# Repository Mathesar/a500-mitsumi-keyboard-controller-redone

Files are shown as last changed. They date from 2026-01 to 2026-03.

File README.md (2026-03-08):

# Mitsumi PCB A-500 redone

This is a remake ("redone") of the Amiga 500 Mitsumi keyboard controller.

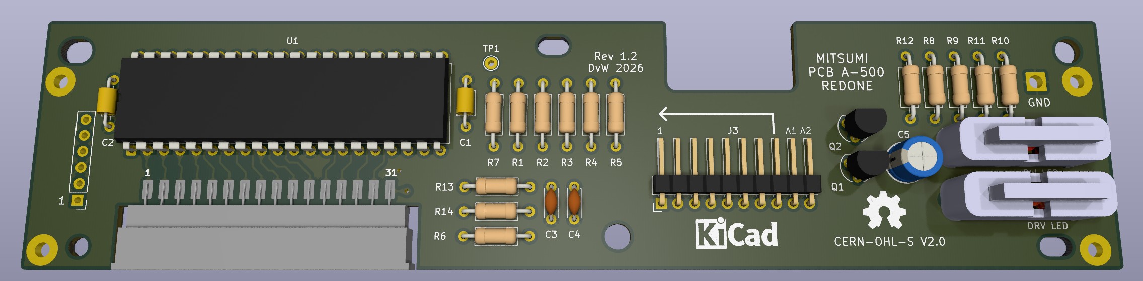
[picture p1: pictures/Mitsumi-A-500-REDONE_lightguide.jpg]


The original Amiga 500 uses a MOS 6570 microcontroller that is no longer produced and therefore getting exceedingly rare. They are also starting to fail, resulting in the dreaded "blinking CAPS-LOCK" issue. Since there was no open-source / open-hardware replacement design available I decided to make my own.

This is a completely new "from scratch" design that uses a Microchip [PIC18F4520](https://www.microchip.com/en-us/product/pic18f4520) microcontroller. I chose this type as it is available in a DIP40 package that is easy to solder by hand. It also gives this new redone keyboard controller a very similar look like the original controller. 

Lastly, what I like about the PIC18F4520 is that it is an 8bit microcontroller with modest capabilities not unlike the MOS 6570. It would bother me a bit to use a 50MHz+ 32bit ARM processor that is magnitudes faster than the Amiga's 68000 CPU just to scan a keyboard.

## Features

* Completely independent design.
* Fully compatible with the original Mitsumi keyboard controller.
* Debouncing filter.
* Anti-ghosting filter.
* Dimming power LED that also works on older Amiga 500 motherboard revisions.
* Through-hole design using currently available components for a retro look.
* Uses three 5mm x 2mm x 7mm LEDs instead of the unobtanium Commodore 15mm LED.
* Optionally, a 3D printed lightguide can be used to give a cleaner LED look.

## Molex ZIF connector

The original keyboard controller uses a Molex right angle ZIF connector to connect to the keyboard matrix membrane. This connector is very hard (impossible?) to get. I therefore used the straight version of this connector, the [Molex 39-53-2315](https://www.molex.com/en-us/products/part-detail/39532315). This connector is soldered on the edge of the circuitboard. This causes the entry point of the connector to sit lower than the original. This puts some strain on the flat cable and one should therefore take care when assembling the keyboard.

## LED brightness tuning

Modern LEDs are way brighter than the LEDs that Commodore used back in the days.
If the LEDs turn out too bright, they can be tuned by changing some resistor values.

### Drive LED

The drive LEDs can be tuned by simply changing resistor R12. Higher values lower the brightness.

### Power LED

The power LEDs are a bit special. One cannot simply use a larger than original current limiting resistor. This is because of the power LED dimming function on later revisions of the Amiga 500. Simply using a larger current limiting resistor would make the dimming hardly noticeable causing the power LEDs to always shine at seemingly full brightness.

To solve this, the circuit around Q1/Q2 has been added. This circuit detects when the LEDs should be dimmed or not. If the Amiga turns the LEDs on (full brightness on later revisions), only Q2 will conduct and deliver current to the LEDs via both R10 and R11. When the Amiga turns the LEDs off (dimmed on later revisions), only Q1 will conduct and current to the LEDs is only delivered via R10. The power LEDs will be dimmed.

For a good dimming effect, R10 should be about 4 times bigger than R11. This gives a current ratio of about 1:5.
In order to reduce or increase the brightness both resistors should thus be changed. Higher values lower the brightness.

## Building

The board is a completely through-hole design and should thus be easy to build. 
The BOM contains some partnumbers for the resistors but one can use any brand. None of the components are critical.

For the LEDs one can use 3 5mm x 2mm LEDs. These are still available. The top of these LEDs should sit above 12.3mm above the PCB. 
Alternatively, 3mm ("flat top") LEDs can be used combined with a 3D printed light guide. I had mine printed by JLC3DP using the 8001 "translucent" resin. The LEDs should be soldered close to the PCB to make this fit. Be aware though that the 8001 resin is not UV resistant on the long term. However, so far my light guides are holding up well.

To connect the keyboard controller to the main board a 300mm 8pin DuPont cable assembly can be used. The pinheader for this cable has 10 pins instead of 8. The extra pins are "auxiliary" pins meant for future expansions and not currently implemented. Therefore connect the keyboard cable only to pins 1..8 as indicated by the arrow.

## Firmware and programming

The firmware was developed using [MPLAB X ide v6.25](https://www.microchip.com/en-us/tools-resources/develop/mplab-x-ide).
The code is written in C for the [XC8 compiler](https://www.microchip.com/en-us/tools-resources/develop/mplab-xc-compilers/xc8).
These tools are freely available from [Microchip](https://www.microchip.com).

## Pictures

Picture of lightguide version mounted on an mechanical keyboard. The drive lightpipe has been removed to show the 3 flat top 3mm LEDs. You can also see how the groundstrap is supposed to connect. 
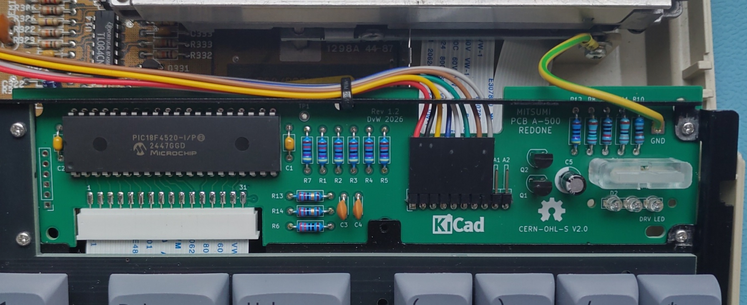
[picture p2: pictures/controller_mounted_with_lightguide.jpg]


Render of version using three 5mm x 2mm LEDs
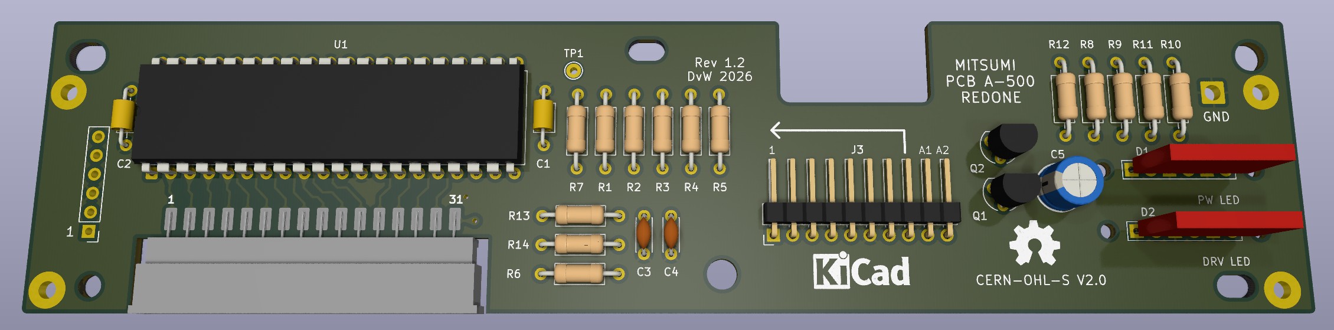
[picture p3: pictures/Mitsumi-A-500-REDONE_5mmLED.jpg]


Closeup of version with 5mm x 2mm LEDs. On this picture I glued the LEDs together using an UV curable glue. These LEDs were originally fully transparant but I sanded the tops with sandpaper to get a more diffuse look.
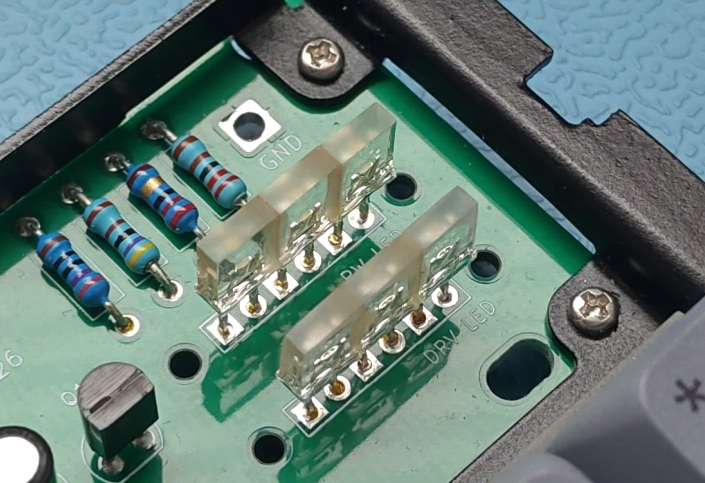
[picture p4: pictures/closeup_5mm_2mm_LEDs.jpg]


## Licenses

The hardware is licensed under [CERN OHL-S V2.0](https://cern-ohl.web.cern.ch/).
The firmware is licensed under [GNU GPL V3](https://www.gnu.org/licenses/gpl-3.0.en.html).

## Acknowledgements

The KiCad keyboard schematic symbol was originally done by [Scott Lawrence](https://github.com/BleuLlama/AmigaSchematics/tree/master/A500_kyb_Mitsumi).

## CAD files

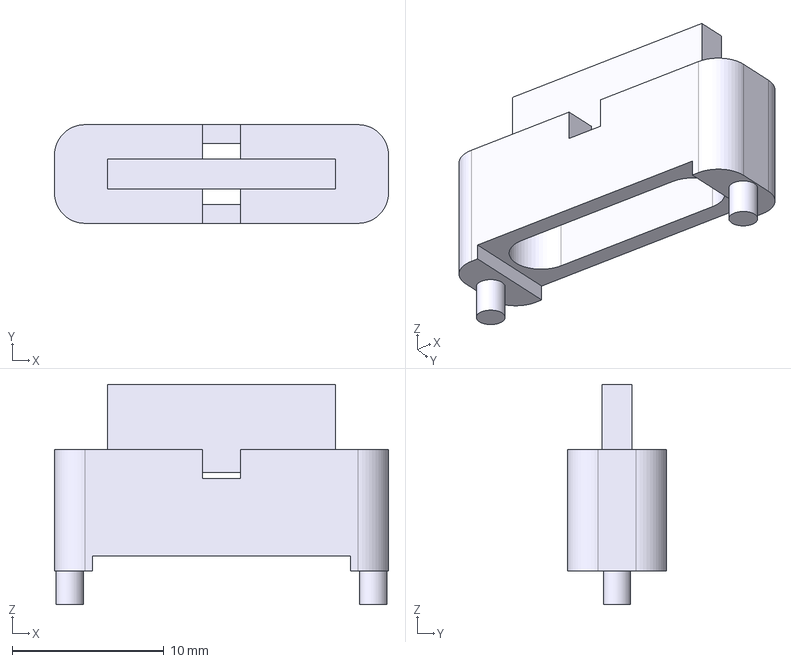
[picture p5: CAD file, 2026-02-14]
cad/lightpipe.step
22.0 x 6.50 x 14.5 mm

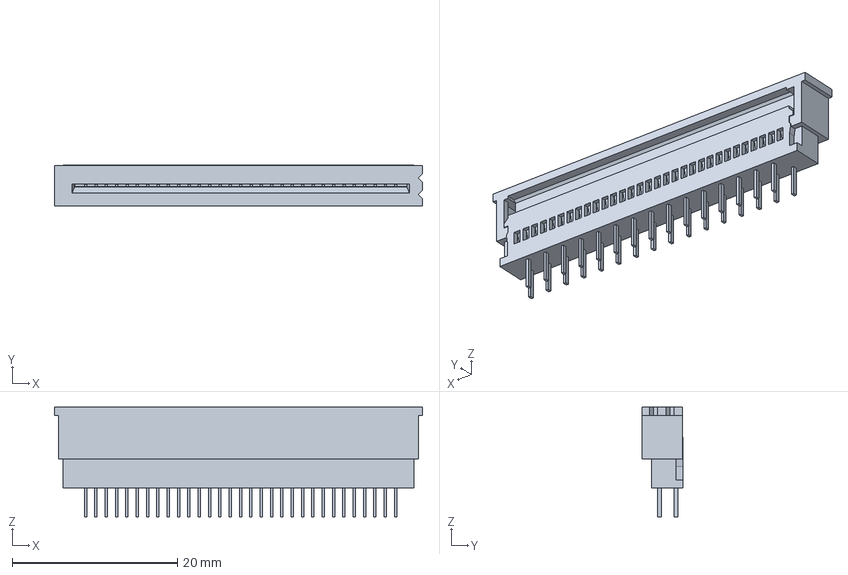
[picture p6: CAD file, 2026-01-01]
kicad/3D/0039532315.stp
44.5 x 5.00 x 13.3 mm

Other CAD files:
cad/lightpipe.FCStd

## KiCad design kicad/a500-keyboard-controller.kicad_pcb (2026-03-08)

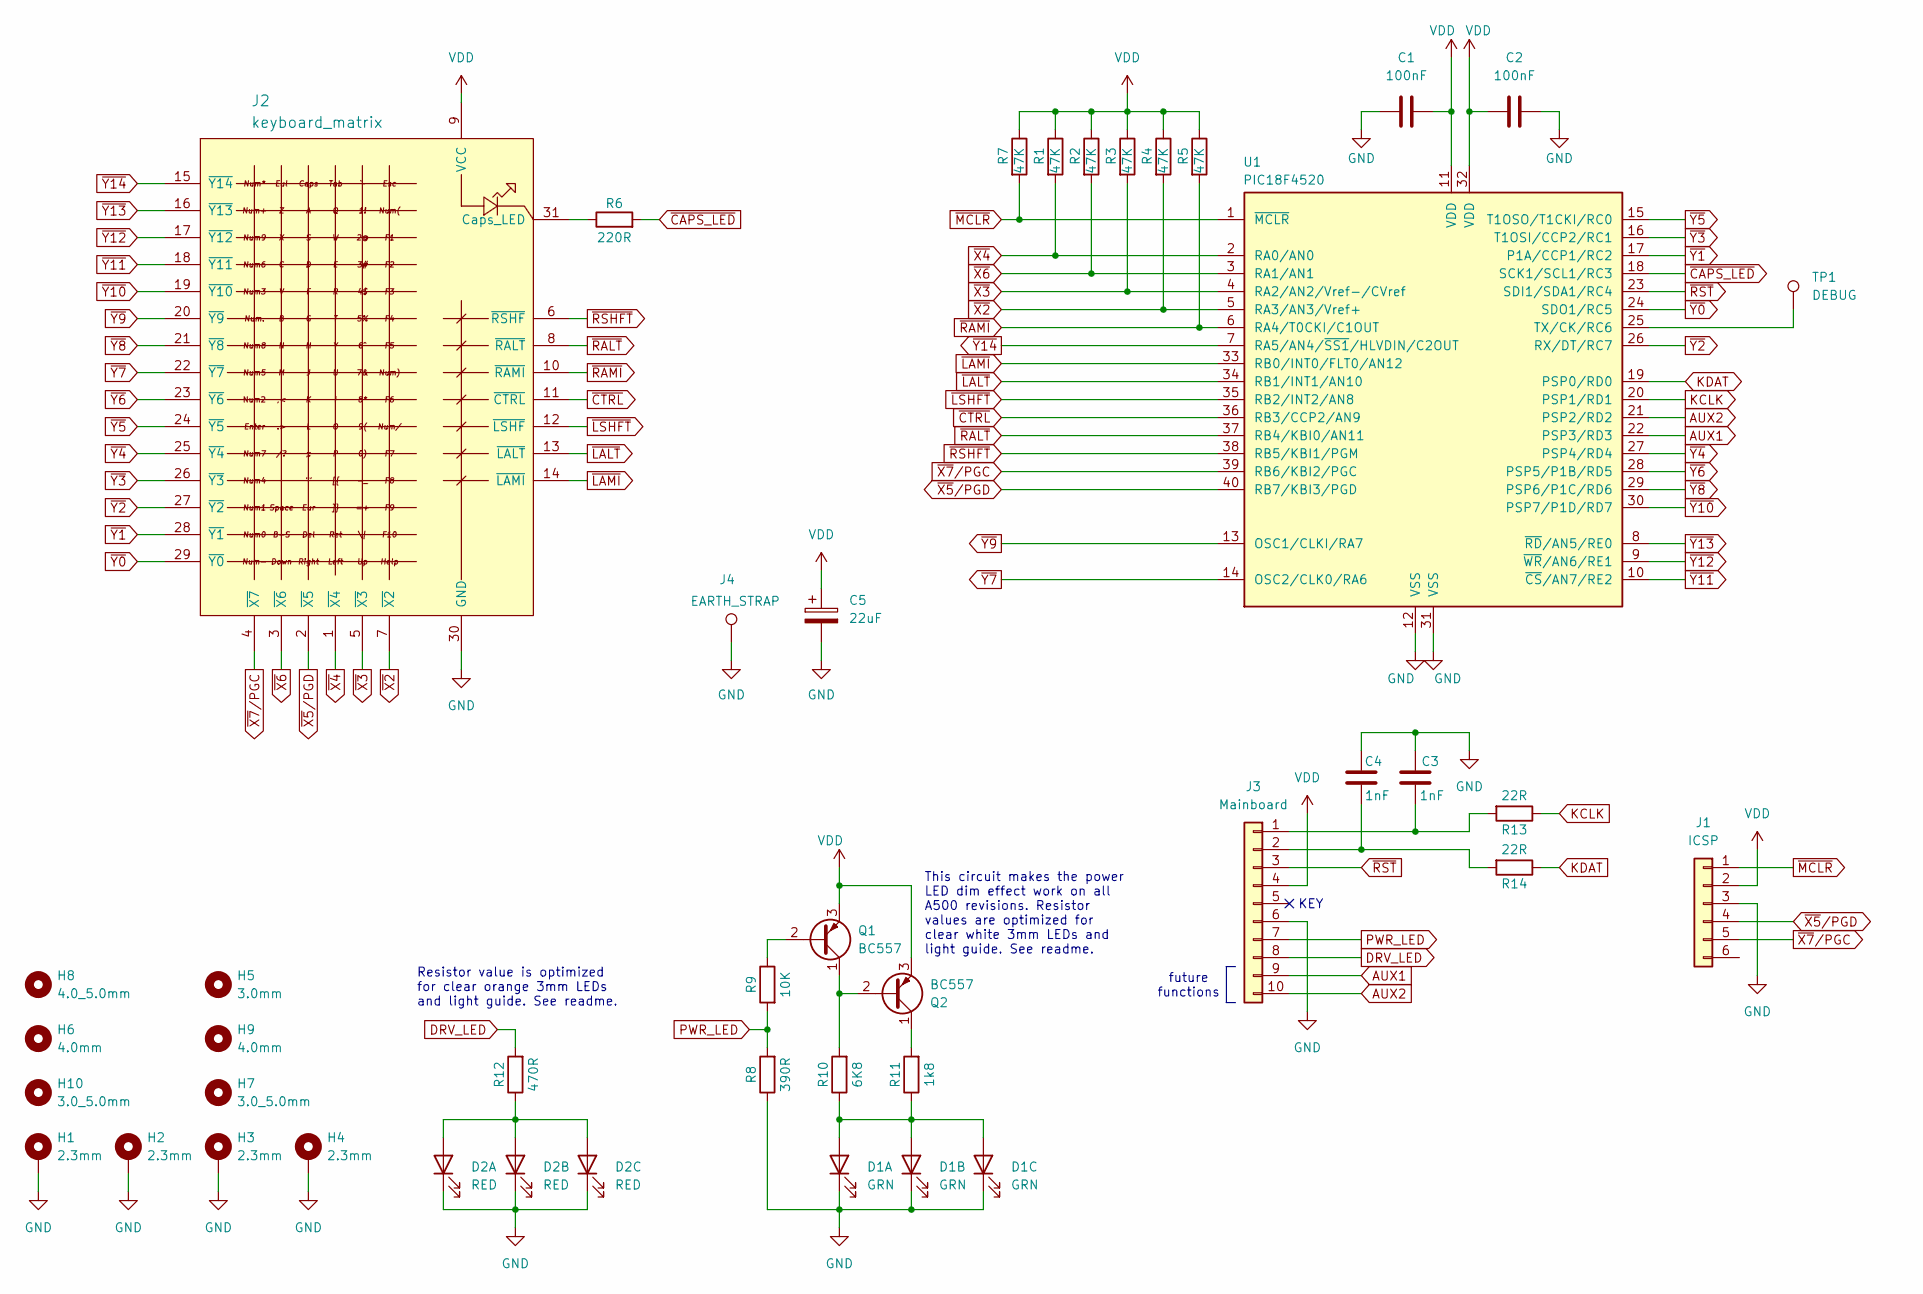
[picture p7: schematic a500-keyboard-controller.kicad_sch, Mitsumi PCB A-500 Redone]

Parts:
C1, C2: 100nF; C_Axial_L3.8mm_D2.6mm_P7.50mm_Horizontal; MPN A104K15X7RF5UAA
C3, C4: 1nF; C_Disc_D4.3mm_W1.9mm_P5.00mm; MPN D102K20Y5PH63J5R
C5: 22uF; CP_Radial_D6.3mm_P2.50mm; MPN EEA-GA1C220H
D1: GRN; A500_triple_LED_equivalent
D2: RED; A500_triple_LED_equivalent
H1, H2, H3, H4: 2.3mm; MountingHole_2.3mm_Pad
H5: 3.0mm; MountingHole_3mm
H6, H9: 4.0mm; MountingHole_4mm
H7, H10: 3.0_5.0mm; mountinghole_3.0_5.0
H8: 4.0_5.0mm; mountinghole_4.0_5.0
J1: ICSP; PinHeader_1x06_P2.54mm_Vertical
J2: keyboard_matrix; 39-53-2315; MPN 39-53-2315
J3: Mainboard; PinHeader_1x10_P2.54mm_Horizontal
J4: EARTH_STRAP; SolderWire-1.5sqmm_1x01_D1.7mm_OD3mm
Q1, Q2: BC557; TO-92_HandSolder_modified
R1, R2, R3, R4, R5, R7: 47K; R_Axial_DIN0207_L6.3mm_D2.5mm_P10.16mm_Horizontal; MPN MF0207FTE52-47K
R6: 220R; R_Axial_DIN0207_L6.3mm_D2.5mm_P10.16mm_Horizontal; MPN MF0207FTE52-220R
R8: 390R; R_Axial_DIN0207_L6.3mm_D2.5mm_P10.16mm_Horizontal; MPN MF0207FTE52-390R
R9: 10K; R_Axial_DIN0207_L6.3mm_D2.5mm_P10.16mm_Horizontal; MPN MF0207FTE52-10K
R10: 6K8; R_Axial_DIN0207_L6.3mm_D2.5mm_P10.16mm_Horizontal; MPN MF0207FTE52-6K8
R11: 1k8; R_Axial_DIN0207_L6.3mm_D2.5mm_P10.16mm_Horizontal; MPN MF0207FTE52-1K8
R12: 470R; R_Axial_DIN0207_L6.3mm_D2.5mm_P10.16mm_Horizontal; MPN MF0207FTE52-470R
R13, R14: 22R; R_Axial_DIN0207_L6.3mm_D2.5mm_P10.16mm_Horizontal; MPN MF0207FTE52-22R
TP1: DEBUG; TestPoint_THTPad_D2.0mm_Drill1.0mm
U1: PIC18F4520; DIP-40_W15.24mm; MPN PIC18F4520-I/P

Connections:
AUX1: J3.9, U1.22 (PSP3/RD3)
AUX2: J3.10, U1.21 (PSP2/RD2)
DRV_LED: J3.8, R12.2
GND: C1.1, C2.2, C3.2, C4.2, C5.2, D1.1 (K), D1.3 (K), D1.5 (K), D2.1 (K), D2.3 (K), D2.5 (K), H1.1, H2.1, H3.1, H4.1, J1.3, J2.30 (GND), J3.6, J4.1, R8.1, U1.12 (VSS), U1.31 (VSS)
KCLK: R13.1, U1.20 (PSP1/RD1)
KDAT: R14.1, U1.19 (PSP0/RD0)
unnamed: D1.2 (A), D1.4 (A), D1.6 (A), R10.1, R11.1
unnamed: D2.2 (A), D2.4 (A), D2.6 (A), R12.1
unnamed: J2.31 (Caps_LED), R6.1
unnamed: C3.1, J3.1, R13.2
unnamed: C4.1, J3.2, R14.2
unnamed: Q1.2 (B), R9.1
unnamed: Q1.1 (C), Q2.2 (B), R10.2
unnamed: Q2.1 (C), R11.2
unnamed: TP1.1, U1.25 (TX/CK/RC6)
PWR_LED: J3.7, R8.2, R9.2
VDD: C1.2, C2.1, C5.1, J1.2, J2.9 (VCC), J3.4, Q1.3 (E), Q2.3 (E), R1.1, R2.1, R3.1, R4.1, R5.1, R7.1, U1.11 (VDD), U1.32 (VDD)
~CAPS_LED: R6.2, U1.18 (SCK1/SCL1/RC3)
~CTRL: J2.11 (~CTRL), U1.36 (RB3/CCP2/AN9)
~LALT: J2.13 (~LALT), U1.34 (RB1/INT1/AN10)
~LAMI: J2.14 (~LAMI), U1.33 (RB0/INT0/FLT0/AN12)
~LSHFT: J2.12 (~LSHF), U1.35 (RB2/INT2/AN8)
~MCLR: J1.1, R7.2, U1.1 (~MCLR)
~RALT: J2.8 (~RALT), U1.37 (RB4/KBI0/AN11)
~RAMI: J2.10 (~RAMI), R5.2, U1.6 (RA4/T0CKI/C1OUT)
~RSHFT: J2.6 (~RSHF), U1.38 (RB5/KBI1/PGM)
~RST: J3.3, U1.23 (SDI1/SDA1/RC4)
~X2: J2.7 (~X2), R4.2, U1.5 (RA3/AN3/Vref+)
~X3: J2.5 (~X3), R3.2, U1.4 (RA2/AN2/Vref-/CVref)
~X4: J2.1 (~X4), R1.2, U1.2 (RA0/AN0)
~X5/PGD: J1.4, J2.2 (~X5), U1.40 (RB7/KBI3/PGD)
~X6: J2.3 (~X6), R2.2, U1.3 (RA1/AN1)
~X7/PGC: J1.5, J2.4 (~X7), U1.39 (RB6/KBI2/PGC)
~Y0: J2.29 (~Y0), U1.24 (SDO1/RC5)
~Y1: J2.28 (~Y1), U1.17 (P1A/CCP1/RC2)
~Y2: J2.27 (~Y2), U1.26 (RX/DT/RC7)
~Y3: J2.26 (~Y3), U1.16 (T1OSI/CCP2/RC1)
~Y4: J2.25 (~Y4), U1.27 (PSP4/RD4)
~Y5: J2.24 (~Y5), U1.15 (T1OSO/T1CKI/RC0)
~Y6: J2.23 (~Y6), U1.28 (PSP5/P1B/RD5)
~Y7: J2.22 (~Y7), U1.14 (OSC2/CLK0/RA6)
~Y8: J2.21 (~Y8), U1.29 (PSP6/P1C/RD6)
~Y9: J2.20 (~Y9), U1.13 (OSC1/CLKI/RA7)
~Y10: J2.19 (~Y10), U1.30 (PSP7/P1D/RD7)
~Y11: J2.18 (~Y11), U1.10 (~CS/AN7/RE2)
~Y12: J2.17 (~Y12), U1.9 (~WR/AN6/RE1)
~Y13: J2.16 (~Y13), U1.8 (~RD/AN5/RE0)
~Y14: J2.15 (~Y14), U1.7 (RA5/AN4/~SS1/HLVDIN/C2OUT)

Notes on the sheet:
KEY
future functions
Resistor value is optimized for clear orange 3mm LEDs and light guide. See readme.
This circuit makes the power LED dim effect work on all A500 revisions. Resistor values are optimized for clear white 3mm LEDs and light guide. See readme.

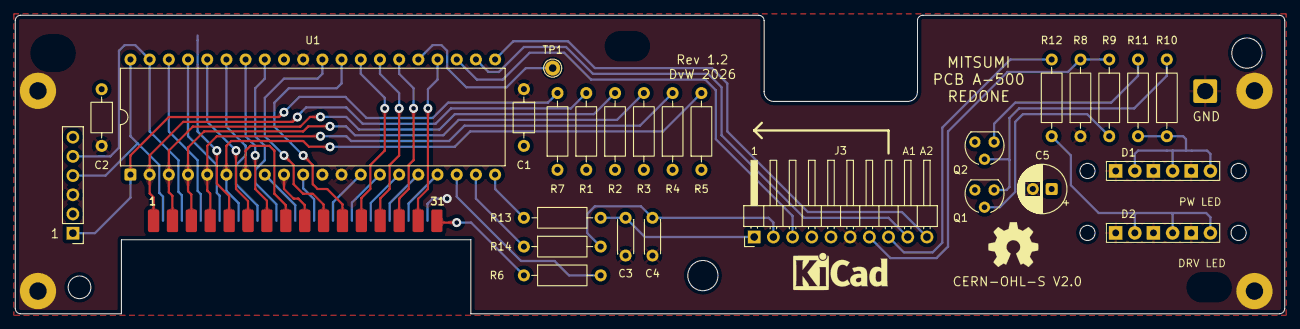
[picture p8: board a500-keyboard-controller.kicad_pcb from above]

Board: 2 copper layers, 168.0 x 39.5 mm, 41 parts (0 on the bottom side), 48 nets.

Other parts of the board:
REF1: KiCad-Logo_5mm_SilkScreen
REF2: OSHW-Symbol_6.7x6mm_SilkScreen

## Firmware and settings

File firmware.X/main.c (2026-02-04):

/*
 *  A500-Mitsumi-controller-redone firmware
 * 
 *  By Dennis van Weeren (2026)
 *  
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
 *  You should have received a copy of the GNU General Public License
 *  along with A500-Mitsumi-controller-redone.  
 *  If not, see <https://www.gnu.org/licenses/>.
 */

// CONFIG1H
#pragma config OSC = INTIO67    // Oscillator Selection bits (Internal oscillator block, port function on RA6 and RA7)
#pragma config FCMEN = OFF      // Fail-Safe Clock Monitor Enable bit (Fail-Safe Clock Monitor disabled)
#pragma config IESO = OFF       // Internal/External Oscillator Switchover bit (Oscillator Switchover mode disabled)

// CONFIG2L
#pragma config PWRT = ON        // Power-up Timer Enable bit (PWRT enabled)
#pragma config BOREN = SBORDIS  // Brown-out Reset Enable bits (Brown-out Reset enabled in hardware only (SBOREN is disabled))
#pragma config BORV = 1         // Brown Out Reset Voltage bits ()

// CONFIG2H
#pragma config WDT = ON         // Watchdog Timer Enable bit (WDT disabled (control is placed on the SWDTEN bit))
#pragma config WDTPS = 256      // Watchdog Timer Postscale Select bits (1:32768)

// CONFIG3H
#pragma config CCP2MX = PORTC   // CCP2 MUX bit (CCP2 input/output is multiplexed with RC1)
#pragma config PBADEN = ON      // PORTB A/D Enable bit (PORTB<4:0> pins are configured as analog input channels on Reset)
#pragma config LPT1OSC = OFF    // Low-Power Timer1 Oscillator Enable bit (Timer1 configured for higher power operation)
#pragma config MCLRE = ON       // MCLR Pin Enable bit (MCLR pin enabled; RE3 input pin disabled)

// CONFIG4L
#pragma config STVREN = ON      // Stack Full/Underflow Reset Enable bit (Stack full/underflow will cause Reset)
#pragma config LVP = OFF        // Single-Supply ICSP Enable bit (Single-Supply ICSP disabled)
#pragma config XINST = OFF      // Extended Instruction Set Enable bit (Instruction set extension and Indexed Addressing mode disabled (Legacy mode))

// CONFIG5L
#pragma config CP0 = OFF        // Code Protection bit (Block 0 (000800-001FFFh) not code-protected)
#pragma config CP1 = OFF        // Code Protection bit (Block 1 (002000-003FFFh) not code-protected)
#pragma config CP2 = OFF        // Code Protection bit (Block 2 (004000-005FFFh) not code-protected)
#pragma config CP3 = OFF        // Code Protection bit (Block 3 (006000-007FFFh) not code-protected)

// CONFIG5H
#pragma config CPB = OFF        // Boot Block Code Protection bit (Boot block (000000-0007FFh) not code-protected)
#pragma config CPD = OFF        // Data EEPROM Code Protection bit (Data EEPROM not code-protected)

// CONFIG6L
#pragma config WRT0 = OFF       // Write Protection bit (Block 0 (000800-001FFFh) not write-protected)
#pragma config WRT1 = OFF       // Write Protection bit (Block 1 (002000-003FFFh) not write-protected)
#pragma config WRT2 = OFF       // Write Protection bit (Block 2 (004000-005FFFh) not write-protected)
#pragma config WRT3 = OFF       // Write Protection bit (Block 3 (006000-007FFFh) not write-protected)

// CONFIG6H
#pragma config WRTC = OFF       // Configuration Register Write Protection bit (Configuration registers (300000-3000FFh) not write-protected)
#pragma config WRTB = OFF       // Boot Block Write Protection bit (Boot block (000000-0007FFh) not write-protected)
#pragma config WRTD = OFF       // Data EEPROM Write Protection bit (Data EEPROM not write-protected)

// CONFIG7L
#pragma config EBTR0 = OFF      // Table Read Protection bit (Block 0 (000800-001FFFh) not protected from table reads executed in other blocks)
#pragma config EBTR1 = OFF      // Table Read Protection bit (Block 1 (002000-003FFFh) not protected from table reads executed in other blocks)
#pragma config EBTR2 = OFF      // Table Read Protection bit (Block 2 (004000-005FFFh) not protected from table reads executed in other blocks)
#pragma config EBTR3 = OFF      // Table Read Protection bit (Block 3 (006000-007FFFh) not protected from table reads executed in other blocks)

// CONFIG7H
#pragma config EBTRB = OFF      // Boot Block Table Read Protection bit (Boot block (000000-0007FFh) not protected from table reads executed in other blocks)

// #pragma config statements should precede project file includes.
// Use project enums instead of #define for ON and OFF.

#include <xc.h>
#include "main.h"
#include "matrix.h"
#include "keyboard.h"

#define MATRIX_SCAN_INTERVAL_MS     10
#define RESET_DEBOUNCE_TIME_MS      50
#define RESET_PULSE_DURATION_MS     500

#ifndef NDEBUG

#define DBG_PERIOD_US 832   // ~1200 baud
#define DBG_BIT_OUT(bit)    {   us_timer_set(DBG_PERIOD_US);        \
                                if(!(bit)){DEBUG = 0;}              \
                                if(bit){DEBUG = 1;}                 \
                                us_timer_wait();                    };

// 1200 baud, bit-banged serial debug output
void debug_out(uint8_t data)
{
    // startbit
    DBG_BIT_OUT(0);    
    // data
    DBG_BIT_OUT(data&0x01);
    DBG_BIT_OUT(data&0x02);
    DBG_BIT_OUT(data&0x04);
    DBG_BIT_OUT(data&0x08);
    DBG_BIT_OUT(data&0x10);
    DBG_BIT_OUT(data&0x20);
    DBG_BIT_OUT(data&0x40);
    DBG_BIT_OUT(data&0x80);
    // stopbit
    DBG_BIT_OUT(1);    
}

void putch(char c)
{
    debug_out(c);
}

#endif

// initialize system
void init(void)
{
    // 8MHz
    OSCCONbits.IRCF = 0b111; 
    
    // disable comparators
    CMCONbits.CM = 0b111;
        
    // disable analog inputs    
    ADCON1bits.PCFG = 0b1111;
    
    //configure porta
    LATA = 0x00;
    TRISA = 0xff;
    
    // configure portb
    LATB = 0x00;
    TRISB = 0xff;
    INTCON2bits.RBPU = 0; // enable pullups
    
    // configure portc 
    LATC = 0x40;  // debug/TXD high, CAPS LED on  
    TRISC = 0xb7; // C3 is CAPS LED, C6 is debug/TXD
    
    // configure portd
    LATD = 0x00;
    TRISD = 0xf3; // D2,D3 are AUX outputs
    
    // configure porte
    LATE = 0x00;
    TRISE = 0x07;
    
    // configure timer0 in 16bit mode, 128 micro-seconds per count
    T0CON = 0b10000111;
    
    //configure timer1 in 16bit mode, 4 micro-seconds per count
    T1CON = 0b10110001;
}

void main(void) 
{
    timer_t reset_debounce_timer, reset_timer, scan_timer;
    uint8_t key_code;
    bool    ctrl_amiga_amiga_detected = false;
    
    enum state_t
    {
        POWERUP = 0,
        POWERUP_SYNCED,
        START_SCAN,
        SCAN,
        OUT_OF_SYNC,
        RESET_HOST,
        RESET_HOST_WAIT_PULSE,
        RESET_HOST_WAIT_RELEASE
    };
    
    enum state_t state = POWERUP;
    
    // initialize system
    init();
    
#ifndef NDEBUG
    printf("A500 Mitsumi redone\n");
#endif
                
    // main loop
    while(1)       
    {
        // Check for ctrl-amiga-amiga reset outside main state machine,
        // set state directly to RESET_HOST if so.
        if( (!CTRL) && (!LEFT_AMIGA) && (!RIGHT_AMIGA) && (!ctrl_amiga_amiga_detected))
        {
            if( (timer_get() - reset_debounce_timer) > ms_to_timer(RESET_DEBOUNCE_TIME_MS) )
            {
                state = RESET_HOST;
                ctrl_amiga_amiga_detected = true;
            }               
        }
        else
        {
            reset_debounce_timer = timer_get();
        }
                
        // main state machine
        switch(state)
        {
            // We come here after a reset.
            case POWERUP:
                // send sync pulse and wait for host to respond      
                if(keyboard_synchronize())
                    state = POWERUP_SYNCED;
                
                break;
                
            // Power-up synchronization achieved.
            case POWERUP_SYNCED:
                // send "ïnitiate power-up key stream" code
                if(!keyboard_send(POWERUP_KEY_STREAM))
                    state = POWERUP;
                 
                // send "terminate key stream" code
                if(!keyboard_send(TERMINATE_KEY_STREAM))
                    state = POWERUP;
                
                // turn off CAPS-LOCK LED
                CAPS_LOCK = 1;
                
                // we are now ready to scan the keyboard matrix
                state = START_SCAN;
                                
                break;  

            // Start scanning.
            case START_SCAN:
                // reset timer
                scan_timer = timer_get();
                
                state = SCAN;
                
                break;
                
            // Scan matrix.
            case SCAN:
                if( (timer_get() - scan_timer) > ms_to_timer(MATRIX_SCAN_INTERVAL_MS) )
                {
                    scan_timer = timer_get();
#ifdef NDEBUG
                    DEBUG = 1;
#endif
                    // scan matrix
                    matrix_scan();                  
                    
                    // extract key codes
                    matrix_decode();
#ifdef NDEBUG
                    DEBUG = 0;
#endif
                }       
                
                // send keycodes
                key_code = keyboard_get_buffer();
                if(key_code != KEYBOARD_BUFFER_EMPTY)
                {
                    if(!keyboard_send(key_code))
                    {
                        state = OUT_OF_SYNC;  
                    }
                }
                break;
             
            // We are out of sync with the host computer.           
            case OUT_OF_SYNC:                
                // send sync pulse and wait for host to respond                
                if(keyboard_synchronize())
                {
                    // we are synchronized again, send "lost sync" code
                    if(keyboard_send(LOST_SYNC))
                    {
                        // resend garbled code
                        if(keyboard_send(key_code))
                        {
                            state = START_SCAN;
                        }
                    }                     
                }               
                break;
                
            // Reset requested.
            case RESET_HOST:                
                // assert reset to host computer (A500)               
                HOST_RESET = 0;
                
                // assert reset to host computer (big box)       
                KCLK = 0;
                
                // turn on CAPS-LOCK LED
                CAPS_LOCK = 0;
                
                // set reset pulse timer
                reset_timer = timer_get();
                
                state = RESET_HOST_WAIT_PULSE;
                
                break;
            
            // Wait for reset pulse to finish.
            case RESET_HOST_WAIT_PULSE:                
                if( (timer_get() - reset_timer) > ms_to_timer(RESET_PULSE_DURATION_MS) )
                {
                    state = RESET_HOST_WAIT_RELEASE;
                }
                break;
                                        
            // Wait for user to release ctrl-amiga-amiga.   
            case RESET_HOST_WAIT_RELEASE:      
                if( CTRL || LEFT_AMIGA || RIGHT_AMIGA )
                {
                    // Now reset ourself as well.
                    // This will also release the host reset.
                    RESET();
                }         
                break;
                
            // We should never, ever come here.
            default:    
                RESET();                
                break;
        }     
        
        // clear watchdog
        CLRWDT();        
    }

    // And here too.
    RESET();
}

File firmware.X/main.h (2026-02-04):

/*
 *  A500-Mitsumi-controller-redone firmware
 * 
 *  By Dennis van Weeren (2026)
 *  
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
 *  You should have received a copy of the GNU General Public License
 *  along with A500-Mitsumi-controller-redone.  
 *  If not, see <https://www.gnu.org/licenses/>.
 */

#ifndef MAIN_H
#define	MAIN_H

// set below define to disable debugging
#define NDEBUG

#ifndef NDEBUG
#include <stdio.h>
#endif

// keyboard matrix row IO definitions
#define MATRIX_Y0       TRISCbits.TRISC5
#define MATRIX_Y1       TRISCbits.TRISC2
#define MATRIX_Y2       TRISCbits.TRISC7
#define MATRIX_Y3       TRISCbits.TRISC1
#define MATRIX_Y4       TRISDbits.TRISD4
#define MATRIX_Y5       TRISCbits.TRISC0
#define MATRIX_Y6       TRISDbits.TRISD5
#define MATRIX_Y7       TRISAbits.TRISA6
#define MATRIX_Y8       TRISDbits.TRISD6
#define MATRIX_Y9       TRISAbits.TRISA7
#define MATRIX_Y10      TRISDbits.TRISD7
#define MATRIX_Y11      TRISEbits.TRISE2
#define MATRIX_Y12      TRISEbits.TRISE1
#define MATRIX_Y13      TRISEbits.TRISE0
#define MATRIX_Y14      TRISAbits.TRISA5

// special key IO definitions
#define LEFT_AMIGA      PORTBbits.RB0
#define LEFT_ALT        PORTBbits.RB1
#define LEFT_SHIFT      PORTBbits.RB2
#define CTRL            PORTBbits.RB3
#define RIGHT_ALT       PORTBbits.RB4
#define RIGHT_SHIFT     PORTBbits.RB5
#define RIGHT_AMIGA     PORTAbits.RA4

// other IO
#define DEBUG           LATCbits.LATC6
#define KDAT_WRITE      TRISDbits.TRISD0
#define KDAT_READ       PORTDbits.RD0
#define KCLK            TRISDbits.TRISD1
#define CAPS_LOCK       LATCbits.LATC3
#define HOST_RESET      TRISCbits.TRISC4

// micro-second timer macro's, resolution=4us, max=255ms
#define us_timer_set(us)            {TMR1 = (uint16_t)(65536UL-(((us)+3UL)/4UL));PIR1bits.TMR1IF = 0;}
#define us_timer_expired()          (PIR1bits.TMR1IF)
#define us_timer_wait()             {while(!PIR1bits.TMR1IF);}

// shared timer macro's, resolution = 128us
#define timer_get()                 (TMR0)
#define ms_to_timer(ms)             (((uint32_t)ms*1000UL)/128UL)
typedef uint16_t timer_t;

#endif	/* MAIN_H */

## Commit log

2026-01-01 This version sent to fabrication
    [0039532315.stp, a500-keyboard-controller.kicad_pcb, a500-keyboard-controller.kicad_sch]
2026-01-02 updated BOM
    [a500-keyboard-controller.kicad_pcb, a500-keyboard-controller.kicad_sch]
2026-01-09 - fixed oscillator speed
    - added printf functionality via DEBUG pin
    [main.c, main.h]
2026-01-17 added caps-lock handling
    fixed many small bugs
    [main.c, main.h]
2026-01-17 fixed reset behaviour
    created proper defines for some constants
    [main.c]
2026-01-18 - added watchdog
    - fixed bug in matrix_decode()
    [main.c]
2026-01-18 fixed ghost detection algorithm
    [main.c]
2026-01-21 modified shape for better hand solderability
2026-01-21 bigger footprint for bulk capacitor
    bumped revision
    [a500-keyboard-controller.kicad_sch]
2026-01-21 larger margin around ground pads
    Moved ICSP connector
    added teardrops to SMD pads
    optimized some tracks so we can move host cable connector
    [a500-keyboard-controller.kicad_pcb]
2026-01-24 host cable now connects to right angle pin header
    This is version 1.1 and has been sent to production
    [a500-keyboard-controller.kicad_pcb, a500-keyboard-controller.kicad_sch]
2026-02-01 fixed reset behavior
    general timer now has higher resolution
    [main.c, main.h]
2026-02-11 - fixed LED footprint dimensions
    - completely reworked power LED circuit
    [a500-keyboard-controller.kicad_pcb, a500-keyboard-controller.kicad_sch]
2026-02-11 moved OSHW logo a bit, this version sent to fabrication
    [a500-keyboard-controller.kicad_pcb]
2026-02-14 added FreeCAD model for lightpipe
    [lightpipe.FCStd, lightpipe.step]
2026-03-07 changed LED current limiting resistors values
    [a500-keyboard-controller.kicad_pcb, a500-keyboard-controller.kicad_sch]
2026-03-07 added 3D model for lightguide
    [a500-keyboard-controller.kicad_pcb]
2026-03-08 updated some resistor partnumbers
    [a500-keyboard-controller.kicad_pcb, a500-keyboard-controller.kicad_sch]

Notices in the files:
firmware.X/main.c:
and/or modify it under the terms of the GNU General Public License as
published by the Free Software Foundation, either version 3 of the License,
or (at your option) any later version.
